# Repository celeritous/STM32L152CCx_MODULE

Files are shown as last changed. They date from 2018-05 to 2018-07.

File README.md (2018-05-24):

This repository contains the hardware design and firmware templates for Celeritous' newest processor module. This board is based on the ST Micro Cortex M3 Low power STM32L151/152 processor line. 

The current revision is 1.0 and this is the initial commit for review and comment. 

It is being released as Open Source Hardware under the CERN OSH License ver 1.2

All hardware design files are in KiCAD format

All Firmware files will be based on code generated by and for the STM32MXCube code initialization generator and Atollic TrueStudio development environment. 

If users wish to adapt this for use with the Arduino environment they are welcome to do so and we will gladly post it, but our main focus will continue to be based on the TrueStudio environment.

The board has the following features:
1. Small form factor 2.0" x 0.800" (same form factor as STM32F103 "Blue Pill" board but is NOT pin compatible
2. 2 x 20 pin 0.100" pitch headers spaced 0.700 apart (Different spacing than Blue Pill)
3. On-board 3.3V regulator to allow +5V external power
4. External +3.3V power also accepted
5. Board power source is jumper selectable between un-regulated external +5 or external regulated +3.3V
6. Regulated, fused +3.3V power available for user when +5V input is used
7. Power inputs are fused, inverse voltage protected and overvoltage protected
8. 1 USB host/client port with Mini-B connector soldered to board - won't shear off board
9. USB port transient protected, includes 1.5K pull-up 
10. USB port is by default un-powered but may be powered from +5V or +3.3V by installing jumper
11. Board cannot be powered from the USB port. Power is diode isolated to block external USB port sopurces.
12. 65K On-board I2C EEPROM (8K x 8) included. May be upgraded to 256K (32K x 8)
13. 12MHz and 32kHz crystals both included to allow use of RTC
14. VBATT input provided to keep RTC alive during loss of power
15. Power and User defined LEDs
16. On-board I2C Pull-ups included for I2C1 bus which is used for the EEPROM
17. On-Board momentary reset switch
18. On-board Boot mode jumper
19. On-board SWDIO header for ST-Lin V2 Programmer/Debugger module
20. STM32L152CC Processor with 256Kbytes of flash memory and up to 32MHz internal clock speed in LQFP-48 package
21. 4 Layer board for low EMI/RFI

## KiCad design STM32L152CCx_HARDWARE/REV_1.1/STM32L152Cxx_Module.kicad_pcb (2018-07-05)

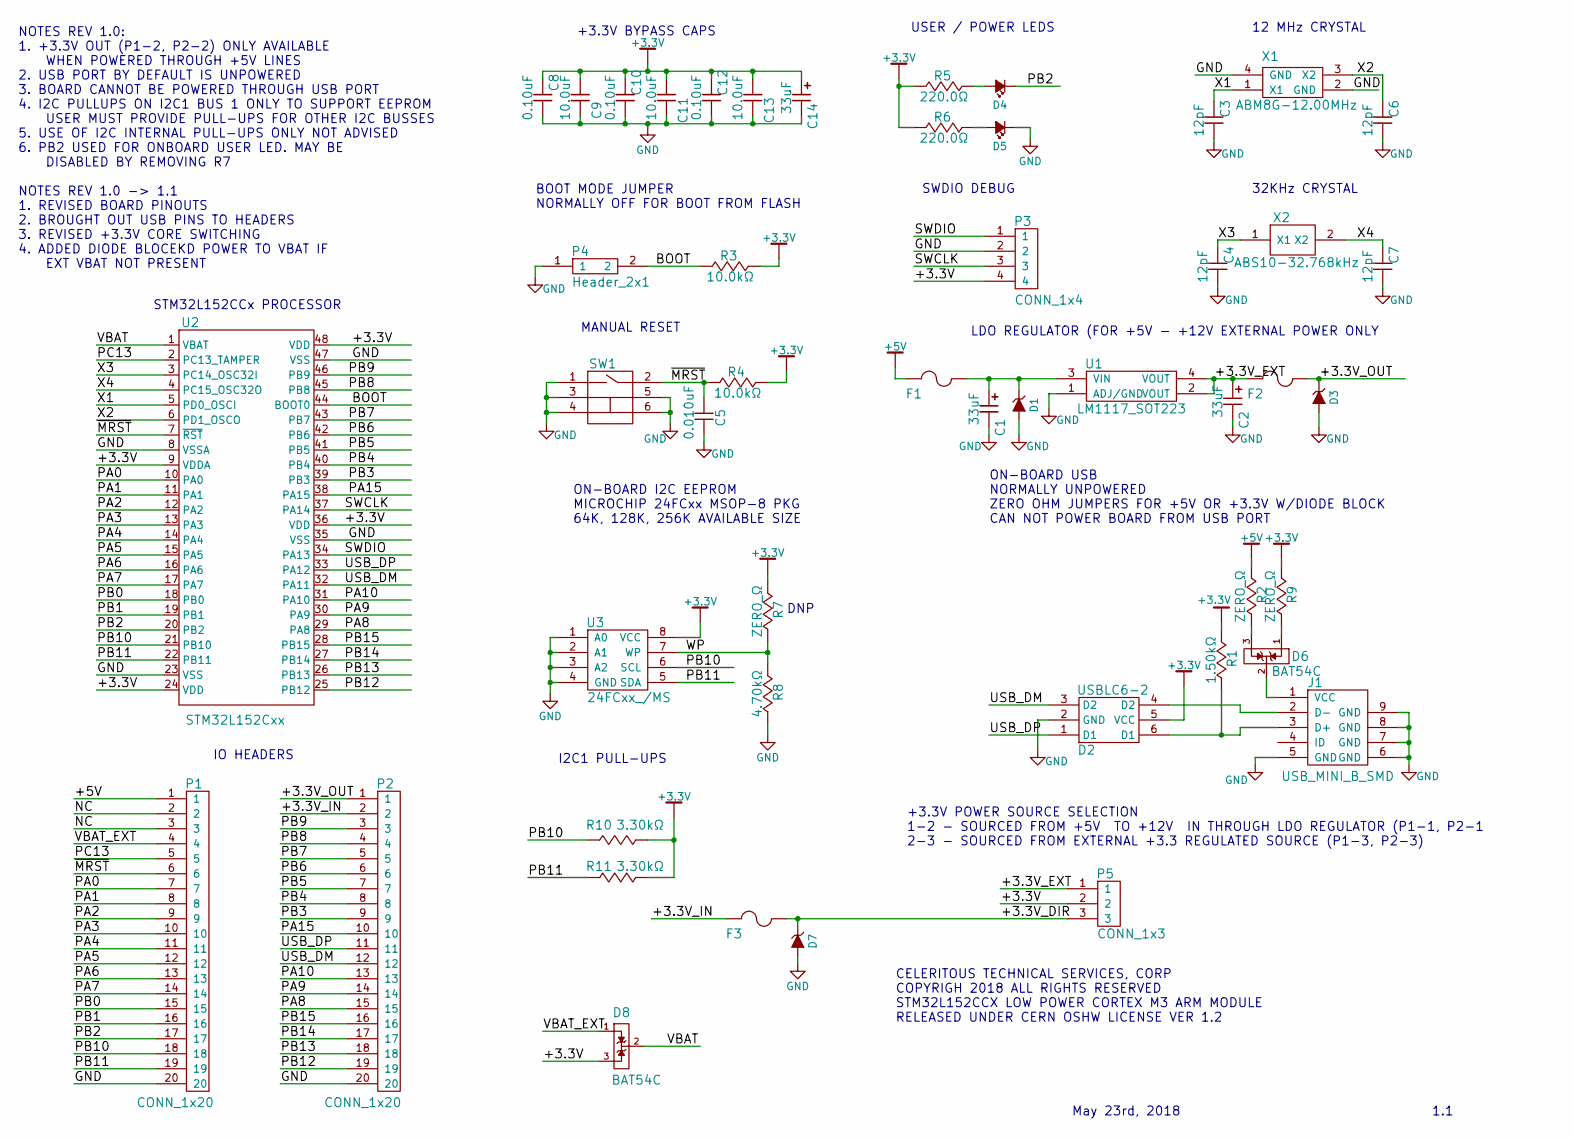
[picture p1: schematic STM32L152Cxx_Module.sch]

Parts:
C1, C2, C14: 33uF; CAPACITOR_TANTALUM_B
C3, C4, C6, C7: 12pF; P0603
C5: 0.010uF; P0603
C8, C10, C12: 0.10uF; P0603
C9, C11, C13: 10.0uF; P0603
D1: SMLJ33ABCT; SOD323F
D2: USBLC6-2; SOT23-6
D3, D7: SMLJ33ABCT; SOD123F
D4, D5: Led_Small; D0805
D6, D8: BAT54C; SOT23-3
F1: FUSE_PTC_.75A_33V; P1210
F2, F3: FUSE_PTC_.5A_33V; P1210
J1: USB_MINI_B_SMD; CONN_USB_UX60-MB
P1, P2: CONN_1x20; HEADER_1X20_100MIL
P3: CONN_1x4; Connector_1x4_100mil_TH
P4: Header_2x1; HEADER_1X2_2MM
P5: CONN_1x3; HEADER_1X3_2MM
R1: 1.50kΩ; P0603
R2, R7, R9: ZERO_Ω; P0603
R3, R4: 10.0kΩ; P0603
R5, R6: 220.0Ω; P0603
R8: 4.70kΩ; P0603
R10, R11: 3.30kΩ; P0603
SW1: PUSHBUTTON_SPST_3X4MM; SWITCH_SPST_3X4MM
U1: LM1117_SOT223; SOT223_4
U2: STM32L152Cxx; QFP48_7X7_0.5
U3: 24FCxx_/MS; MSOP8
X1: ABM8G-12.00MHz; XTAL_3.2X2.5
X2: ABS10-32.768kHz; XTAL_1.8X4.9mm

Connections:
+3.3V: C8.1, C9.1, C10.1, C11.1, C12.1, C13.1, C14.1, D2.5 (VCC), D8.3, P3.4, P5.2, R1.1, R3.2, R4.2, R5.1, R6.1, R7.1, R9.1, R10.2, R11.2, U2.9 (VDDA), U2.24 (VDD), U2.36 (VDD), U2.48 (VDD), U3.8 (VCC)
+5V: F1.1, P1.1, R2.1
/+3.3V_DIR: D7.K, F3.2, P5.3
/+3.3V_EXT: C2.1, F2.1, P5.1, U1.2 (VOUT), U1.4 (VOUT)
/+3.3V_IN: F3.1, P2.2
/+3.3V_OUT: D3.K, F2.2, P2.1
/BOOT: P4.2, R3.1, U2.44 (BOOT0)
/NC: P1.2, P1.3
/PA0: P1.7, U2.10 (PA0)
/PA1: P1.8, U2.11 (PA1)
/PA2: P1.9, U2.12 (PA2)
/PA3: P1.10, U2.13 (PA3)
/PA4: P1.11, U2.14 (PA4)
/PA5: P1.12, U2.15 (PA5)
/PA6: P1.13, U2.16 (PA6)
/PA7: P1.14, U2.17 (PA7)
/PA8: P2.15, U2.29 (PA8)
/PA9: P2.14, U2.30 (PA9)
/PA10: P2.13, U2.31 (PA10)
/PA15: P2.10, U2.38 (PA15)
/PB0: P1.15, U2.18 (PB0)
/PB1: P1.16, U2.19 (PB1)
/PB2: D4.K, P1.17, U2.20 (PB2)
/PB3: P2.9, U2.39 (PB3)
/PB4: P2.8, U2.40 (PB4)
/PB5: P2.7, U2.41 (PB5)
/PB6: P2.6, U2.42 (PB6)
/PB7: P2.5, U2.43 (PB7)
/PB8: P2.4, U2.45 (PB8)
/PB9: P2.3, U2.46 (PB9)
/PB10: P1.18, R10.1, U2.21 (PB10), U3.6 (SCL)
/PB11: P1.19, R11.1, U2.22 (PB11), U3.5 (SDA)
/PB12: P2.19, U2.25 (PB12)
/PB13: P2.18, U2.26 (PB13)
/PB14: P2.17, U2.27 (PB14)
/PB15: P2.16, U2.28 (PB15)
/PC13: P1.5, U2.2 (PC13_TAMPER)
/SWCLK: P3.3, U2.37 (PA14)
/SWDIO: P3.1, U2.34 (PA13)
/USB_DM: D2.3 (D2), P2.12, U2.32 (PA11)
/USB_DP: D2.1 (D1), P2.11, U2.33 (PA12)
/VBAT: D8.2, U2.1 (VBAT)
/VBAT_EXT: D8.1, P1.4
/WP: R7.2, R8.1, U3.7 (WP)
/X1: C3.1, U2.5 (PD0_OSCI), X1.1 (X1)
/X2: C6.1, U2.6 (PD1_OSCO), X1.3 (X2)
/X3: C4.1, U2.3 (PC14_OSC32I), X2.1 (X1)
/X4: C7.1, U2.4 (PC15_OSC32O), X2.2 (X2)
/~MRST: C5.1, P1.6, R4.1, SW1.2, U2.7 (~RST)
GND: C1.2, C2.2, C3.2, C4.2, C5.2, C6.2, C7.2, C8.2, C9.2, C10.2, C11.2, C12.2, C13.2, C14.2, D1.A, D2.2 (GND), D3.A, D5.K, D7.A, J1.5 (GND), J1.6 (GND), J1.7 (GND), J1.8 (GND), J1.9 (GND), P1.20, P2.20, P3.2, P4.1, R8.2, SW1.1, SW1.3, SW1.4, SW1.5, SW1.6, U1.1 (ADJ/GND), U2.8 (VSSA), U2.23 (VSS), U2.35 (VSS), U2.47 (VSS), U3.1 (A0), U3.2 (A1), U3.3 (A2), U3.4 (GND), X1.2 (GND), X1.4 (GND)
unnamed: C1.1, D1.K, F1.2, U1.3 (VIN)
unnamed: D2.4 (D2), J1.2 (D-)
unnamed: D2.6 (D1), J1.3 (D+), R1.2
unnamed: D4.A, R5.2
unnamed: D5.A, R6.2
unnamed: D6.1, R9.2
unnamed: D6.2, J1.1 (VCC)
unnamed: D6.3, R2.2

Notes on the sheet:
DNP
12 MHz CRYSTAL
32KHz CRYSTAL
USER / POWER LEDS
SWDIO DEBUG
LDO REGULATOR (FOR +5V - +12V EXTERNAL POWER ONLY
+3.3V BYPASS CAPS
BOOT MODE JUMPER NORMALLY OFF FOR BOOT FROM FLASH
MANUAL RESET
ON-BOARD USB NORMALLY UNPOWERED ZERO OHM JUMPERS FOR +5V OR +3.3V W/DIODE BLOCK CAN NOT POWER BOARD FROM USB PORT
ON-BOARD I2C EEPROM MICROCHIP 24FCxx MSOP-8 PKG 64K, 128K, 256K AVAILABLE SIZE
CELERITOUS TECHNICAL SERVICES, CORP COPYRIGH 2018 ALL RIGHTS RESERVED STM32L152CCX LOW POWER CORTEX M3 ARM MODULE RELEASED UNDER CERN OSHW LICENSE VER 1.2
May 23rd, 2018
1.1
+3.3V POWER SOURCE SELECTION 1-2 - SOURCED FROM +5V TO +12V IN THROUGH LDO REGULATOR (P1-1, P2-1 2-3 - SOURCED FROM EXTERNAL +3.3 REGULATED SOURCE (P1-3, P2-3)
IO HEADERS
STM32L152CCx PROCESSOR
NOTES REV 1.0: 1. +3.3V OUT (P1-2, P2-2) ONLY AVAILABLE WHEN POWERED THROUGH +5V LINES 2. USB PORT BY DEFAULT IS UNPOWERED 3. BOARD CANNOT BE POWERED THROUGH USB PORT 4. I2C PULLUPS ON I2C1 BUS 1 ONLY TO SUPPORT EEPROM USER MUST PROVIDE PULL-UPS FOR OTHER I2C BUSSES 5. USE OF I2C INTERNAL PULL-UPS 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
I2C1 PULL-UPS

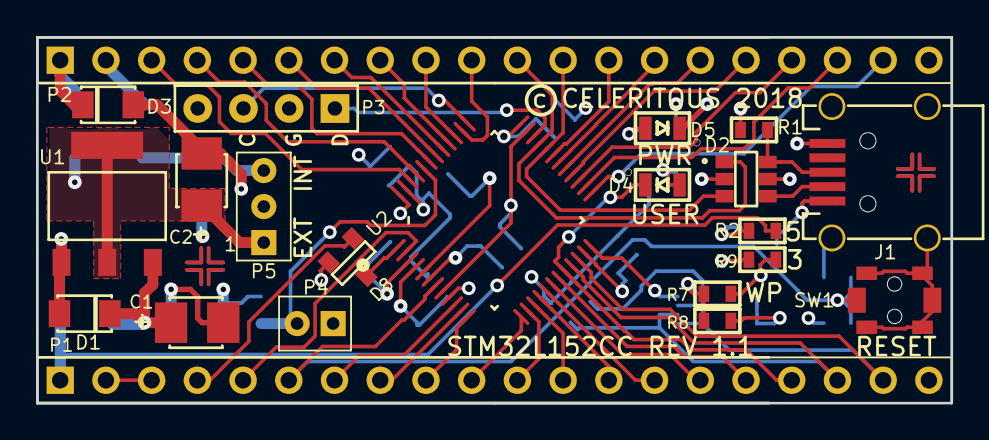
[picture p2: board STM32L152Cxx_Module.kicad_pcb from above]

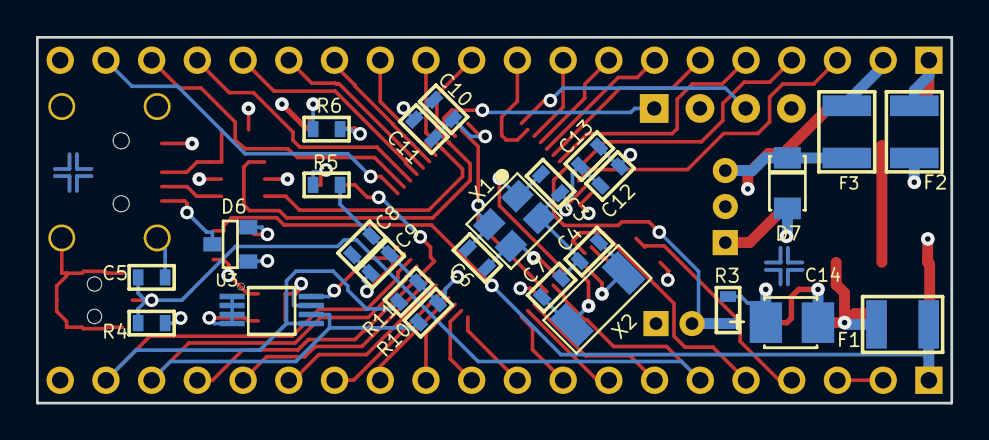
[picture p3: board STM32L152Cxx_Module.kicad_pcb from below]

Board: 4 copper layers, 50.8 x 20.3 mm, 51 parts (26 on the bottom side), 58 nets.

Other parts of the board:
REF01, REF02: FIDUCIAL_TOP
REF03: FIDUCIAL_BOTTOM

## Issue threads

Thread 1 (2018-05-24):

No diode from +3.3V to VBAT to power RTC when no VBAT present

celeritous, 2018-05-24:
Just looking and schematic and writing up initial commit description and I don't have a diode to power the VBAT line if a battery input is not present. Will be added on next commit

celeritous, 2018-06-25:
Corrected in Release 1.1

Closed 2018-06-25.

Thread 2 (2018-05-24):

Some Power rework needed

celeritous, 2018-05-24:
looking at the schematic while writing the description I'm still not happy with the power configuration and selection. Right now if external direct +3.3V is used there is essentially no protection. I will fix that before the next release.

celeritous, 2018-06-25:
Corrected in release 1.1

Closed 2018-06-25.

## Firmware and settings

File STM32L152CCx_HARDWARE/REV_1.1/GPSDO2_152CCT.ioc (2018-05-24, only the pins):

Mcu.UserName=STM32L151CCTx
PA0-WKUP1.Signal=S_TIM2_CH1_ETR
PA1.Signal=S_TIM2_CH2
PA10.Signal=USART1_RX
PA11.Signal=USB_DM
PA12.Signal=USB_DP
PA13.Signal=SYS_JTMS-SWDIO
PA14.Signal=SYS_JTCK-SWCLK
PA2.Signal=ADC_IN2
PA3.Signal=ADC_IN3
PA4.Signal=COMP_DAC1_group
PA5.Signal=COMP_DAC2_group
PA6.Signal=S_TIM3_CH1
PA9.Signal=USART1_TX
PB10.Signal=I2C2_SCL
PB11.Signal=I2C2_SDA
PB6.Signal=I2C1_SCL
PB7.Signal=I2C1_SDA
PC14-OSC32_IN.Signal=RCC_OSC32_IN
PC15-OSC32_OUT.Signal=RCC_OSC32_OUT
PH0-OSC_IN.Signal=RCC_OSC_IN
PH1-OSC_OUT.Signal=RCC_OSC_OUT

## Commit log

2018-05-24 Initial Commit
    For review and comment
    [PREROUTE.kicad_pcb, STM32L152Cxx_Module.dsn, STM32L152Cxx_Module.kicad_pcb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]
2018-06-25 Revision 1.1 with open issues corrected & closed
    [PREROUTE.kicad_pcb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]
2018-07-05 Update 7/4/2018
    [STM32L152Cxx_Module-B.Cu.gbl, STM32L152Cxx_Module-B.Mask.gbs, STM32L152Cxx_Module-B.SilkS.gbo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]

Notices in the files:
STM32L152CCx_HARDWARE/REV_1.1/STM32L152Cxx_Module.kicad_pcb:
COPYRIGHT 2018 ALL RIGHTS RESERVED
